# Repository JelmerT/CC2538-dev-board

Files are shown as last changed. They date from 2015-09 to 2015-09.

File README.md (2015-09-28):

CC2538 Development Board
========================

This is the hardware design of a development board for the [CC2538 chip of Texas Instruments](http://www.ti.com/product/cc2538).



You can find more info about the design and hardware decisions [in this blog post](http://jelmertiete.com/2014/05/07/cc2538-development-board/)

The pcb antenna used in this design has its own repository: https://github.com/JelmerT/Eagle-2.4gHz-folded-dipole-pcb-antenna

I also wrote a handy serial bootloader for this dev-board and other CC2538 (and CC26XX and 13XX) hardware, which you can find here: https://github.com/JelmerT/cc2538-bsl

If you improve this design in any way, consider submitting a pull request or contact me. I'd appreciate it if you let me know if you use this design in a real deployment. I'd like to add your project to this page.

License
-------
**This hardware project is released under the [Creative Commons Share-alike 4.0 International](http://creativecommons.org/licenses/by-sa/4.0/) license.**



(C) Jelmer Tiete - <jelmer@tiete.be>  Analytics (https://github.com/igrigorik/ga-beacon)

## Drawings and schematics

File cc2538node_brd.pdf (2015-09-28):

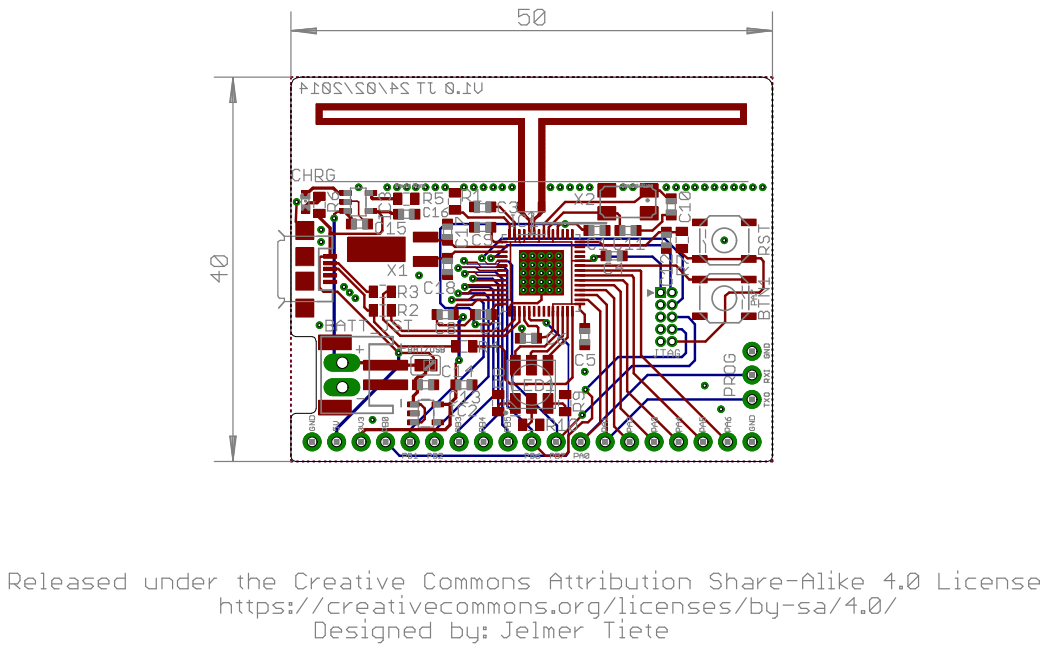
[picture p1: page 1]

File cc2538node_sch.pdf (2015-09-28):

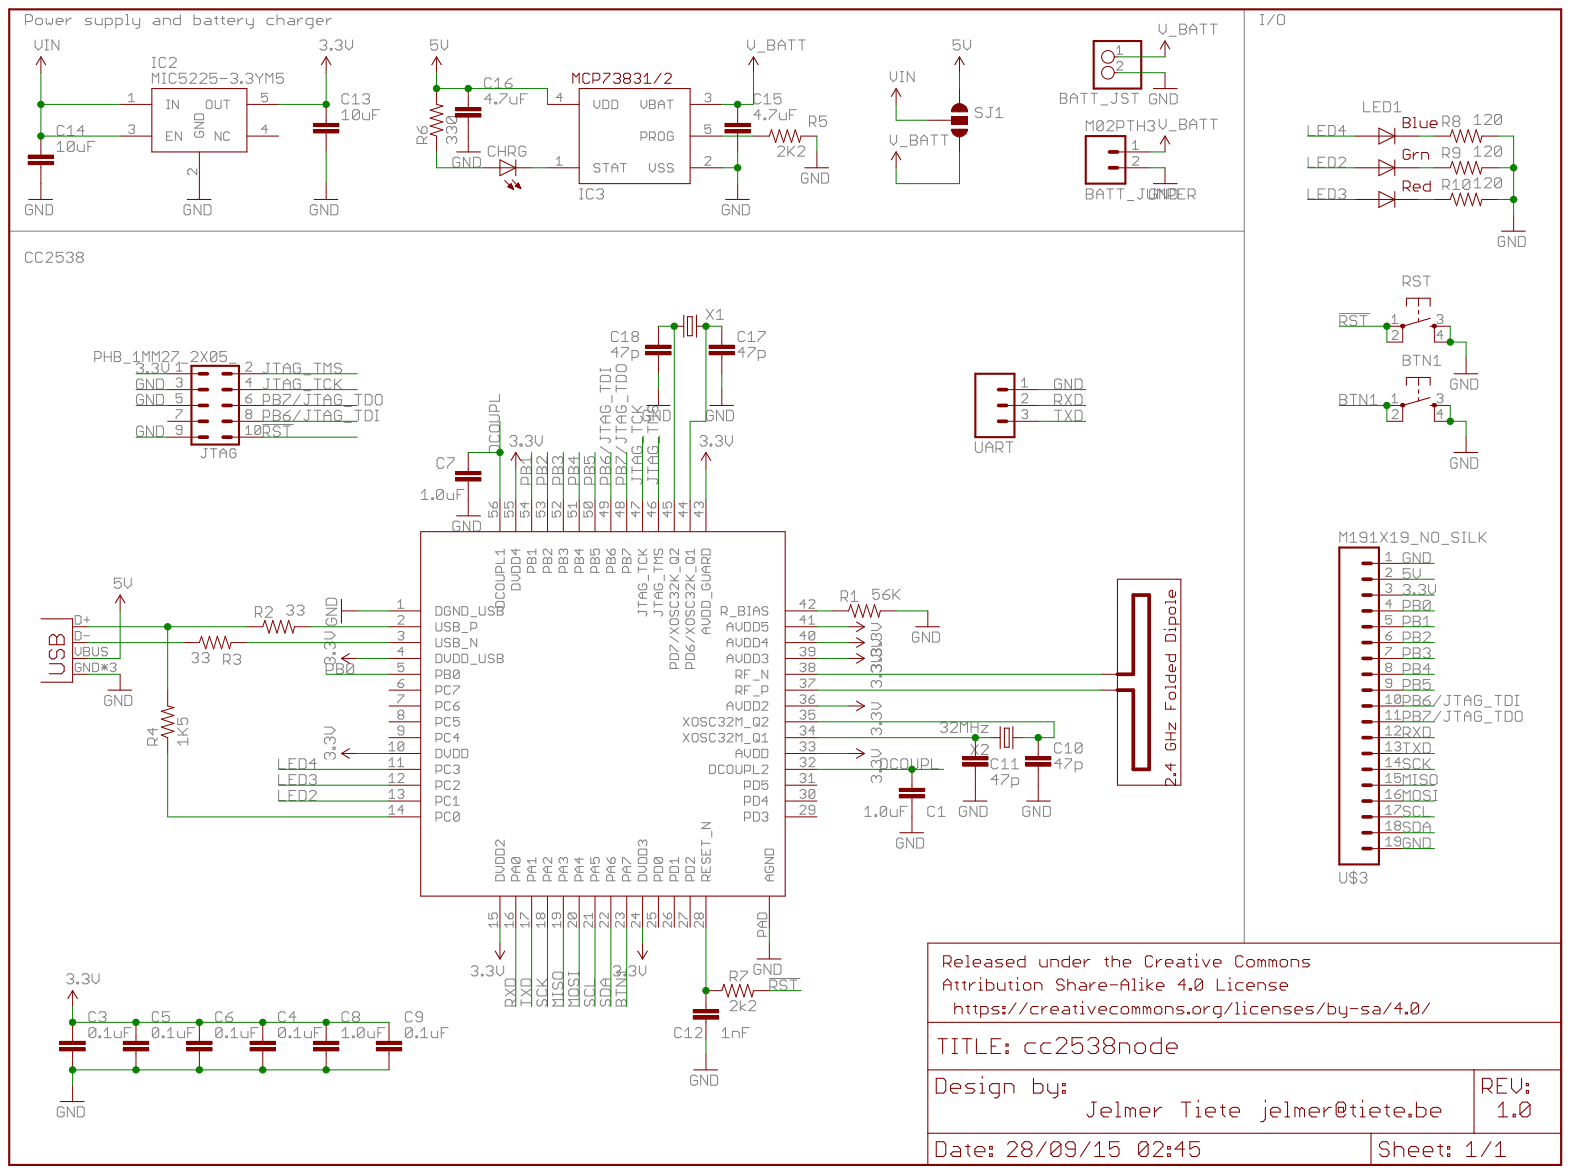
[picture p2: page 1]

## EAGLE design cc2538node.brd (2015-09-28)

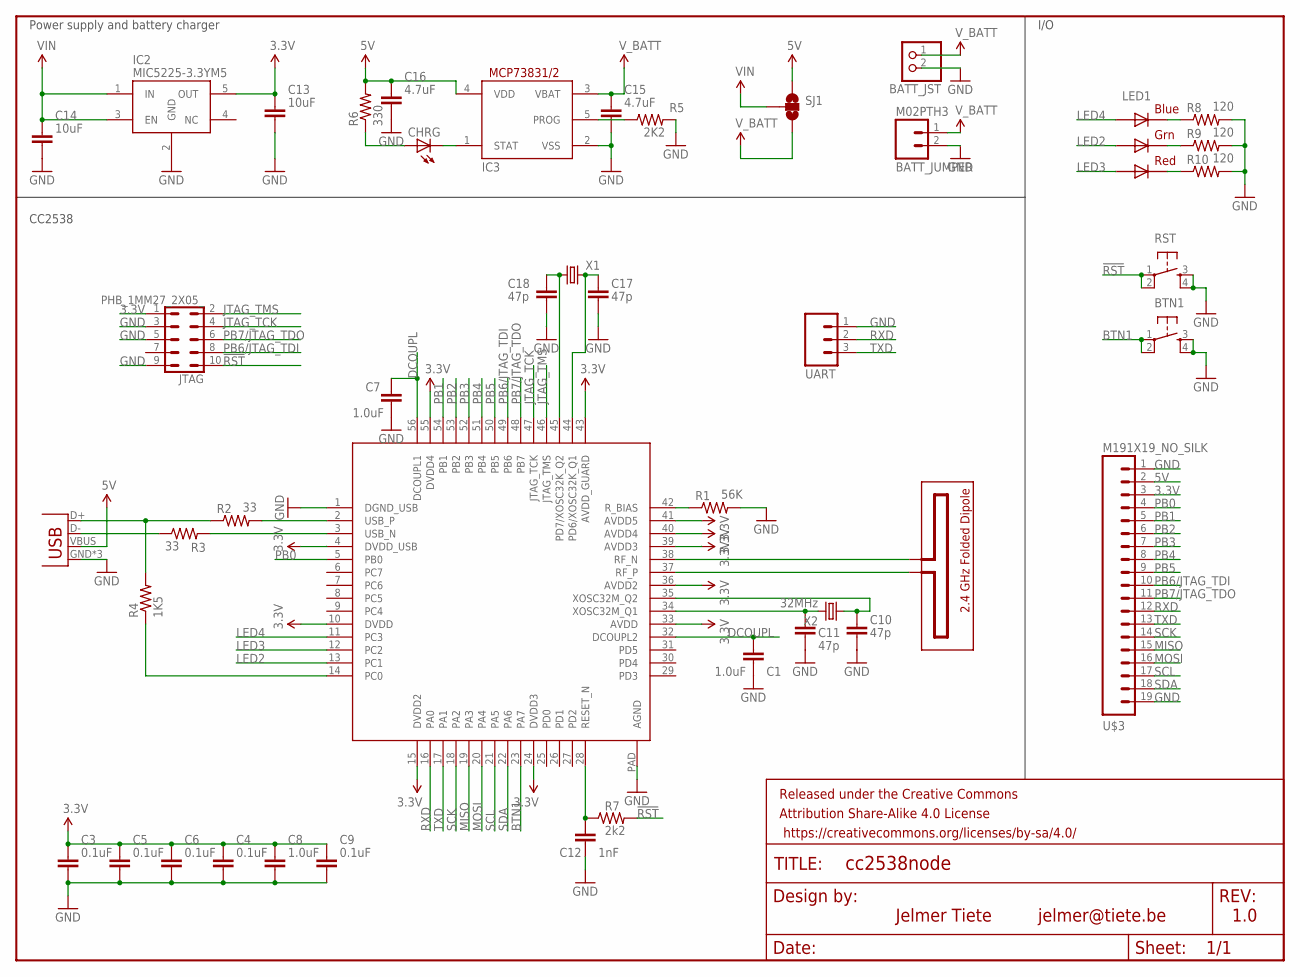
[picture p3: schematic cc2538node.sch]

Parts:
BATT_JST: JST_2PIN-SMT-RA; JST-PH-2-SMT-RA
BATT_JUMPER: M02PTH3; 1X02_LONGPADS
BTN1: TAC_SWITCHSMD; TACTILE_SWITCH_SMD
C1, C7, C8: 1.0uF; C603
C3, C4, C5, C6, C9: 0.1uF; C603
C10, C11, C17, C18: 47p; C603
C12: 1nF; C603
C13, C14: 10uF; C603
C15, C16: 4.7uF; C603
CHRG: LED-0603; LED-603
FRAME2: FRAME-LETTER; CREATIVE_COMMONS
IC1: CC2538; QFN56
IC2: MIC5225-3.3YM5; SOT23-5
IC3: MCP73831/OT; SOT23-5L
JP1: USB-MICROB
JTAG: PHB_1MM27_2X05_; PHB_1MM27_2X05_SNT_NOSILK
LED1: RGBLED5050
R1: 56K; 0805
R2, R3: 33; 0805
R4: 1K5; 0805
R5: 2K2; 0805
R6: 330; 0805
R7: 2k2; 0805
R8, R9, R10: 120; 0805
RST: TAC_SWITCHSMD; TACTILE_SWITCH_SMD
SJ1: SOLDERJUMPER_2WAYPASTE1&2; SJ_3_PASTE1&2
U$1: FOLDED_DIPOLE_ANTENNE_2.4; FOLDED_DIPOLE_2.4
U$3: M191X19_NO_SILK; 1X19_NO_SILK
UART: M031X03_NO_SILK; 1X03_NO_SILK
X1: CRYSTAL32-SMD; CRYSTAL-32KHZ-SMD
X2: 32MHz; CTS406

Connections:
3.3V: C3.1, C4.1, C5.1, C6.1, C8.1, C9.1, C13.1, IC1.4 (DVDD_USB), IC1.10 (DVDD), IC1.15 (DVDD2), IC1.24 (DVDD3), IC1.33 (AVDD), IC1.36 (AVDD2), IC1.39 (AVDD3), IC1.40 (AVDD4), IC1.41 (AVDD5), IC1.43 (AVDD_GUARD), IC1.55 (DVDD4), IC2.5 (OUT), JTAG.1, U$3.3
5V: C16.1, IC3.4 (VDD), JP1.VBUS, R6.2, SJ1.1, U$3.2
!RST: JTAG.10, R7.2, RST.1, RST.2
BTN1: BTN1.1, BTN1.2, IC1.23 (PA7)
DCOUPL: C1.1, C7.1, IC1.32 (DCOUPL2), IC1.56 (DCOUPL1)
GND: BATT_JST.2 (1), BATT_JUMPER.2, BTN1.3, BTN1.4, C1.2, C3.2, C4.2, C5.2, C6.2, C7.2, C8.2, C9.2, C10.2, C11.2, C12.2, C13.2, C14.2, C15.2, C16.2, C17.2, C18.2, IC1.1 (DGND_USB), IC1.PAD (AGND), IC2.2 (GND), IC3.2 (VSS), JP1.GND, JP1.MT1 (GND), JP1.MT2 (GND), JTAG.3, JTAG.5, JTAG.9, R1.2, R5.2, R8.2, R9.2, R10.2, RST.3, RST.4, U$3.1, U$3.19, UART.1
JTAG_TCK: IC1.47 (JTAG_TCK), JTAG.4
JTAG_TMS: IC1.46 (JTAG_TMS), JTAG.2
LED2: IC1.13 (PC1), LED1.1 (GREEN_A)
LED3: IC1.12 (PC2), LED1.2 (RED_A)
LED4: IC1.11 (PC3), LED1.3 (BLUE_A)
MISO: IC1.19 (PA3), U$3.15
MOSI: IC1.20 (PA4), U$3.16
unnamed: IC1.38 (RF_N), U$1.P$1
unnamed: IC1.37 (RF_P), U$1.P$2
unnamed: IC1.3 (USB_N), R3.2
unnamed: IC1.2 (USB_P), R2.2
unnamed: LED1.5 (RED_C), R10.1
unnamed: LED1.6 (GREEN_C), R9.1
unnamed: IC1.42 (R_BIAS), R1.1
unnamed: JP1.D+, R2.1, R4.2
unnamed: JP1.D-, R3.1
unnamed: IC1.14 (PC0), R4.1
unnamed: IC3.5 (PROG), R5.1
unnamed: CHRG.C, IC3.1 (STAT)
unnamed: CHRG.A, R6.1
unnamed: C11.1, IC1.34 (XOSC32M_Q1), X2.3 (2)
unnamed: C10.1, IC1.35 (XOSC32M_Q2), X2.1
unnamed: LED1.4 (BLUE_C), R8.1
unnamed: C17.1, IC1.44 (PD6/XOSC32K_Q1), X1.X2 (2)
unnamed: C18.1, IC1.45 (PD7/XOSC32K_Q2), X1.X1 (1)
PB0: IC1.5 (PB0), U$3.4
PB1: IC1.54 (PB1), U$3.5
PB2: IC1.53 (PB2), U$3.6
PB3: IC1.52 (PB3), U$3.7
PB4: IC1.51 (PB4), U$3.8
PB5: IC1.50 (PB5), U$3.9
PB6/JTAG_TDI: IC1.49 (PB6), JTAG.8, U$3.10
PB7/JTAG_TDO: IC1.48 (PB7), JTAG.6, U$3.11
RESET_N: C12.1, IC1.28 (RESET_N), R7.1
RXD: IC1.16 (PA0), U$3.12, UART.2
SCK: IC1.18 (PA2), U$3.14
SCL: IC1.21 (PA5), U$3.17
SDA: IC1.22 (PA6), U$3.18
TXD: IC1.17 (PA1), U$3.13, UART.3
VIN: C14.1, IC2.1 (IN), IC2.3 (EN), SJ1.2
V_BATT: BATT_JST.1 (2), BATT_JUMPER.1, C15.1, IC3.3 (VBAT), SJ1.3

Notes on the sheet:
jelmer@tiete.be
Jelmer Tiete
1.0
Power supply and battery charger
I/O
CC2538

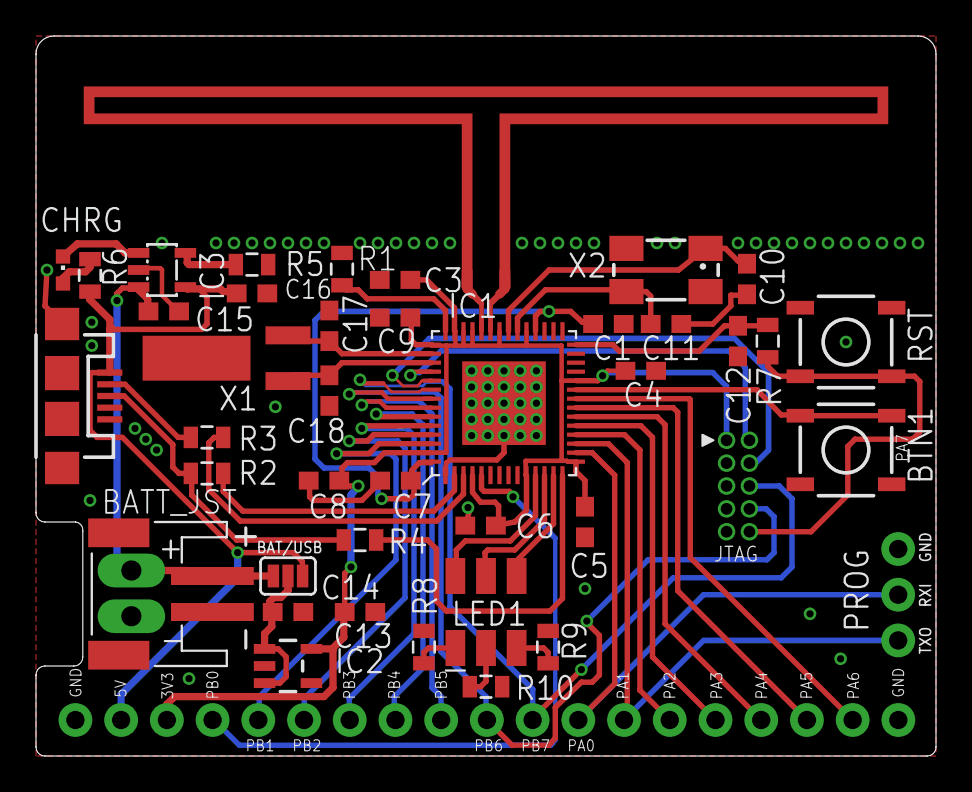
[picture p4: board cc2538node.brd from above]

Board: 2 copper layers, 50.0 x 40.0 mm, 45 parts (0 on the bottom side), 47 nets.

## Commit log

2015-09-24 First commit, including schematic board file readme and pdfs
    [cc2538node.brd, cc2538node.sch]
2015-09-28 Cleaned up schematic and updated pdfs
    [cc2538node.brd, cc2538node.sch]

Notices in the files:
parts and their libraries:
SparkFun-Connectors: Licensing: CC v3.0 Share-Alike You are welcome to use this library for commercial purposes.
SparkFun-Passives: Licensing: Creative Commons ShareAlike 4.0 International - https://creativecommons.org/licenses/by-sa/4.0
